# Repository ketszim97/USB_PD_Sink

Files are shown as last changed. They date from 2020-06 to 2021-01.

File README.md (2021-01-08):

# USB_PD_Sink

### USB C all the things!.

With this breakout of the STUSB4500, you can power all of your devices and electronics projects. From Arduinos to Laptops, USB-C Power Delivery can provide up to **100W (20V @ 5A).**

You can now purchase this from my [Tindie!](https://www.tindie.com/products/ketszim/usb-c-pd-sink-stusb4500/)

This device can store 3 PDOs (Power Delivery Outputs), and upon connection it will attempt to negotiate the highest of these 3. This means that it can operate as a standalone device, without the need for an external microcontroller. The PDO negotiated is shown by the following colors. By default, the device has the following PDOs:

|PDO1|PDO2|PDO3|
|:-----:|:-----:|:-----:|
|5V @ 1.5A|15V @ 1.5A|20V @ 1A|
|Blue|Green|Red|

The PDOs can also be customized by programming the Non-Volatile Memory (NVM) registers via I2C.
The device can also be connected to a microcontroller, to allow on the fly negotiation of the PD contract. To do this the device just needs to be connected via I2C according to the pinout below. Libraries for Arduino exist and are quick and easy to use.

#### Technical Specs
- Controller: STUSB4500
- Output Voltage: 5-20V*
- Output Current: 0-5A*
- LED: Built in LED to display which PDO is negotiated (See above for specifics)
- Protection: ESD and Transient Protection on both Power and USB-C Pins, Discharge of VBUS path on voltage change or capable detach

Designed and manufactured in Canada

*\*Output power is limited by the capability of your charger*



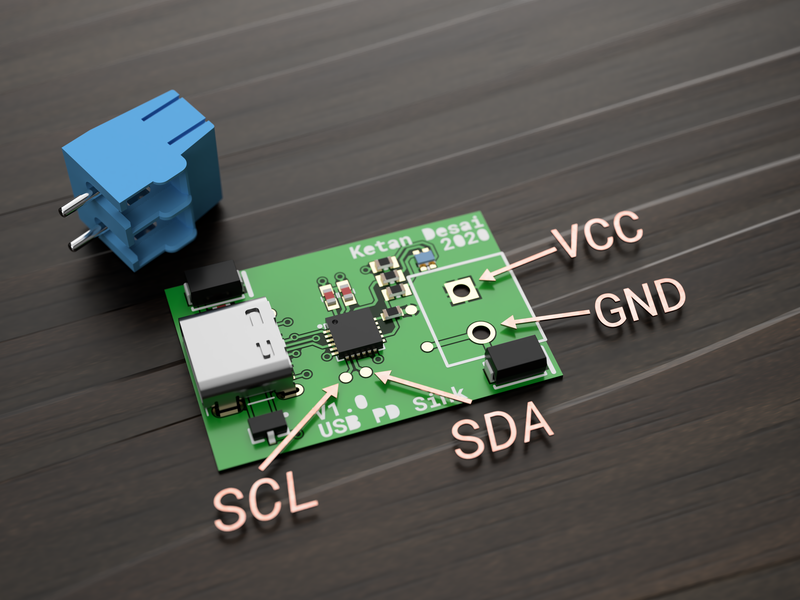
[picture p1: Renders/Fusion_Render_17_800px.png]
Pinout


Fusion Render 1

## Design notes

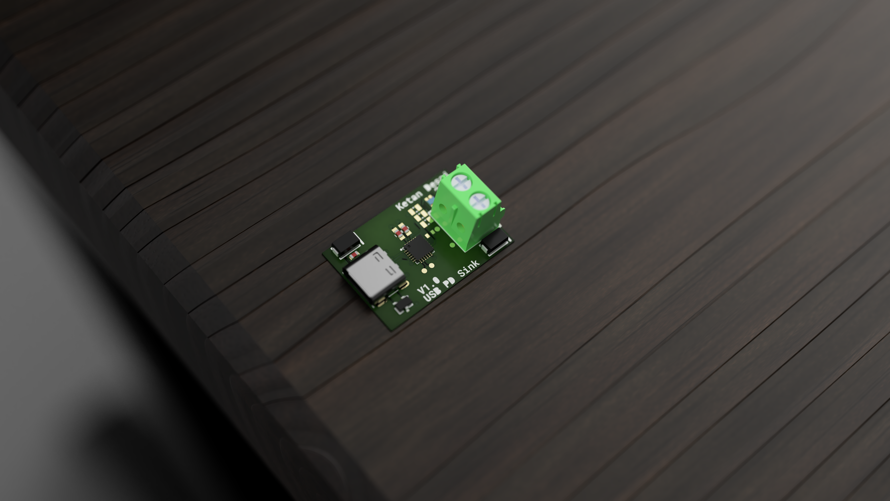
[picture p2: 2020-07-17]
Renders/Fusion_Render_7.png

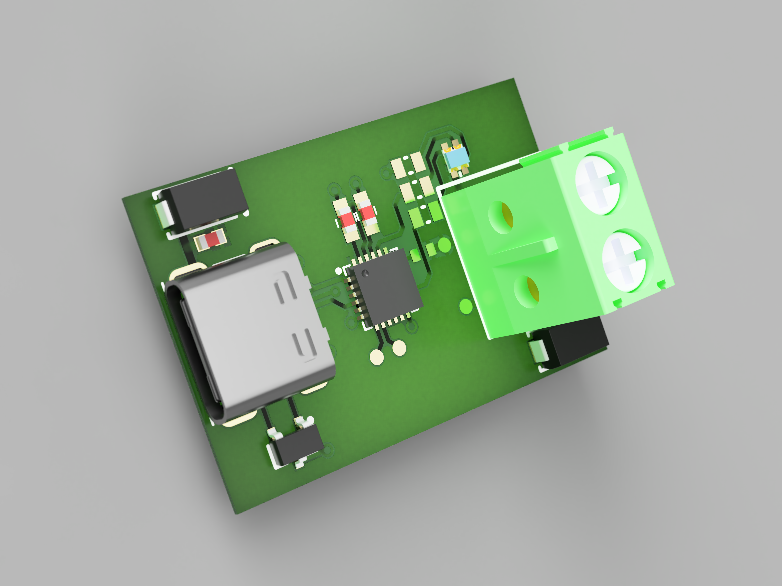
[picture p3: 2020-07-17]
Renders/Fusion_Render_5.png

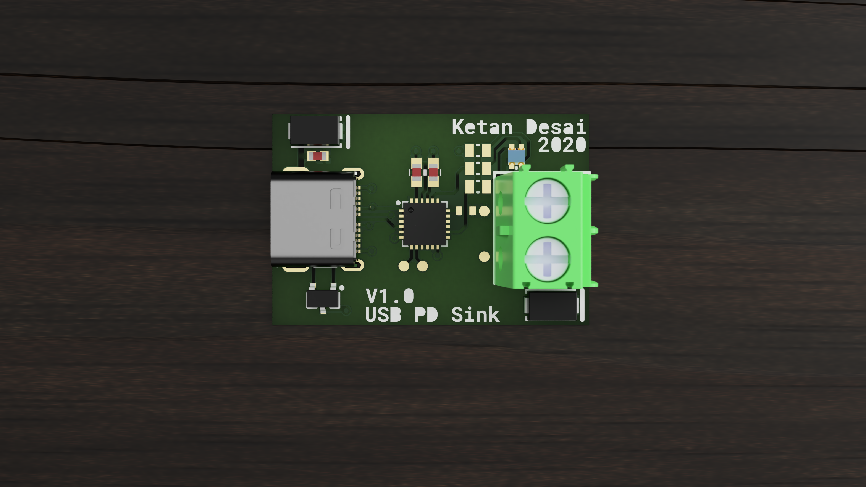
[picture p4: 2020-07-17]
Renders/Fusion_Render_8.png

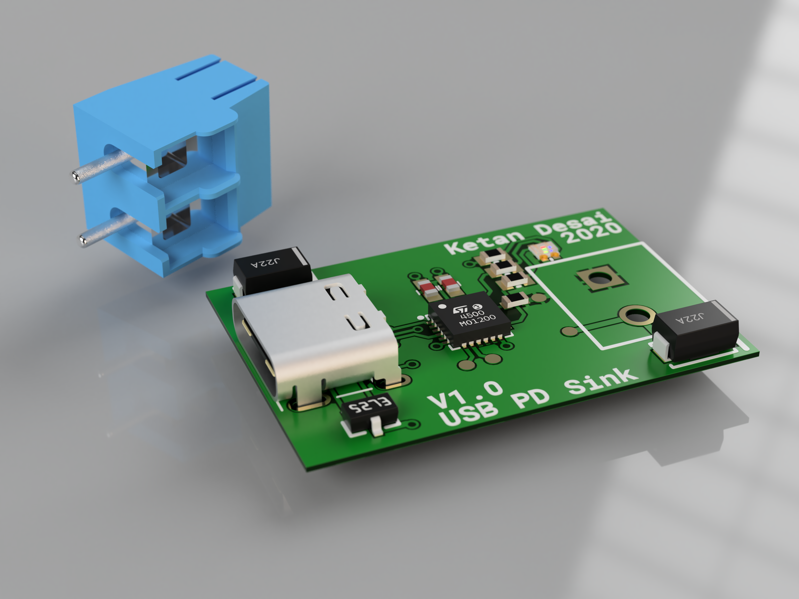
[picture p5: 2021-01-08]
Renders/Fusion_Render_20.png

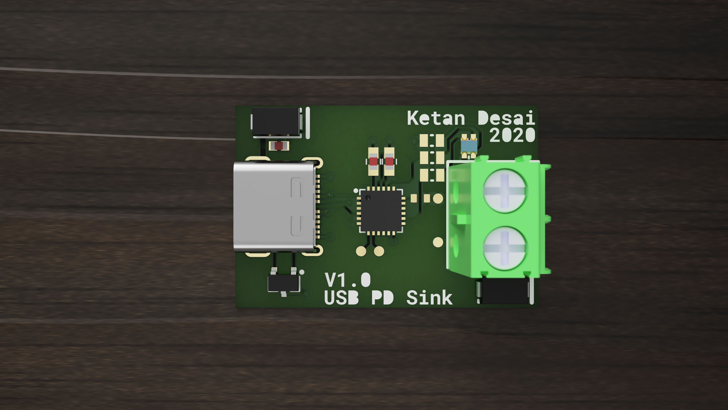
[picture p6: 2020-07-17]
Renders/Fusion_Render_9.png

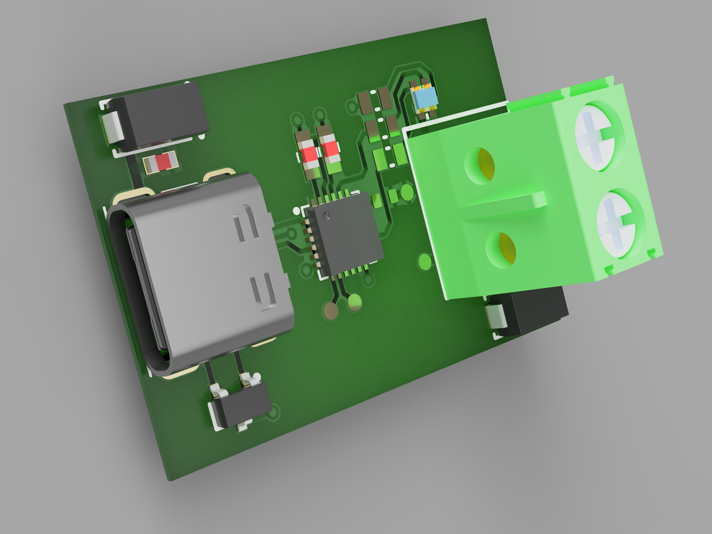
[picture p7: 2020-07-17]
Renders/Fusion_Render_2.png

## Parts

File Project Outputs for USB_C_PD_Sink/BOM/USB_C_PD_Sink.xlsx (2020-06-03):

Comment | Description | Designator | Footprint | LibRef | Quantity | Digi-Key_Part_Number | Manufacturer | Manufacturer Part Number | MP | Supplier 1 | Supplier Part Number 1 | Supplier 2 | Supplier Part Number 2 | Supplier 3 | Supplier Part Number 3
C0603 1uF 10V X7R | Chip Capacitor, 0603, 1uF +/- 0.1uF, 10V, X7R | C1, C2 | C0603-IPC | C0603 1uF 10V X7R | 2 |  |  |  |  | Digi-Key | 1276-1946-1-ND |  |  | LCSC | C5673
4.7uF, 25V, X5R, 0603 | Chip Capacitor, 0603, 4.7uF, 25V, X5R | C3 | C0603-HIGH-DENSITY | C0603 4.7uF 25V X5R | 1 |  |  |  |  | Digi-Key | 490-7203-1-ND | Mouser | 81-GRM188R61E475KE1D | LCSC | C69335
SMAJ22A | Bidirectional TVS DIODE 22V 35.5V DO214AC | D1, D4 | DO-214AC | SMAJ22A | 2 |  | Littlefuse Inc. |  |  | Digi-Key | SMAJ22ALFCT-ND | Mouser | 576-SMAJ22A | LCSC | C148220
RGB | RGB Led 1.6 x 1.6 mm Diffused | D2 | LED_0606_RGB_WURTH | Led_RGB_0606 | 1 |  | Everlight | 19-237/R6GHBHW-C01/2T |  | Digi-Key | 1080-1590-1-ND |  |  | LCSC | C264508 (https://lcsc.com/product-detail/Others_Everlight-Elec-19-237-R6GHBHW-C01-2T_C264508.html)
ESDA25L | Dual Transil Array For ESD Protection in SOT23-3 Vbr = 25V | D3 | SOT23-3L | ESDA25L | 1 |  | STMicroelectronics | ESDA25L |  | Digi-Key | 497-4642-1-ND | Mouser | 511-ESDA25L | LCSC | C95343
Phoenix Contact 1935161 | Terminal Block, 2 Position, 5mm pitch, 18A, 300V, 12-26 AWG | J1 | Phoenix_1935161 | Term Block 2pos | 1 |  | Phoenix Contact | 1935161 |  | Digi-Key | 277-1667-ND
USB C | USB-C USB 3.1 Gen 2, Superspeed+_ Receptacle Connector 24 Position Surface Mount, Right Angle; Through Hole | J2 | Molex USB-C | USB C | 1 | WM12856CT-ND |  |  | 1054500101 | Digi-Key | WM12856CT-ND | Mouser | 538-105450-0101 | LCSC | C134092
R0805 750 5% | Chip Resistor, 0603, 750 ohms, 0.5W | R1, R2, R4 | R0805-High-Density | R0603 750 1% | 3 |  |  |  |  | Digi-Key | P750ADCT-ND | Mouser | 667-ERJ-P06J751V | LCSC | C441948
R0603 1K 1% | RES SMD 1K OHM 1% 1/10W 0603 | R3 | R0603-HIGH-DENSITY | R0603 1K 1% | 1 |  |  |  |  | Digi-Key | RMCF0603FG1K00CT-ND |  |  | LCSC | C21190
STUSB4500 | Standalone USB PD controller with SINK auto-run mode in QFN24 4x4mm | U1 | QFN24 - 4X4MM - PITCH 0.5MM - EXPOSEDPAD | STUSB4500QTR | 1 |  | STMicroelectronics |  |  | Digi-Key | 497-18060-1-ND | Mouser | 511-STUSB4500QTR

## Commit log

2020-05-01 Add Altium Proj, add gitignore
    [USB_C_PD_Sink.PcbDoc, USB_C_PD_Sink.PrjPcb, USB_C_PD_Sink.SchDoc]
2020-05-01 Include component_libraries in the project
    [USB_C_PD_Sink.PrjPcb]
2020-05-01 Added USB C conn and STUSB4500
    [USB_C_PD_Sink.SchDoc]
2020-05-02 Completed schematic capture
    [USB_C_PD_Sink.PcbDoc, USB_C_PD_Sink.PrjPcb, USB_C_PD_Sink.SchDoc]
2020-05-02 Added board outline
    [USB_C_PD_Sink.PcbDoc]
2020-05-04 Added initial placement
    [USB_C_PD_Sink.PcbDoc]
2020-05-15 Completed PCB layout
    [USB_C_PD_Sink.PcbDoc]
2020-05-15 Added gerber outputs. Added outline to keep out
    [USB_C_PD_Sink.PcbDoc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]
2020-05-17 Added fixed gerber outputs
    [USB_C_PD_Sink.PrjPcb]
2020-06-03 Updated BOM
    [USB_C_PD_Sink.PcbDoc, USB_C_PD_Sink.SchDoc, USB_C_PD_Sink.xlsx]
